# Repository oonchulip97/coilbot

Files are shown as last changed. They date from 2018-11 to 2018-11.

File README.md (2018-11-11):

# Overview
This solenoid winder is able to produce solenoids which are suitable to be used as actuators.

## Boards and Motors
 - Arduino Uno R3
 - Arduino Motor Shield L298P
 - Servo Motor Tower Pro 9G 180
 - Stepper Motor Nema17 12V
   
## Software
 - Arduino IDE (tested using version 1.8.5)
 
## Photos
 
 
 
 
# Setup
 1. Design and manufacture solenoid spool supporter to connect the solenoid spool to the shaft of the stepper motor.
 2. Assemble the solenoid spool and solenoid spool supporter to the shaft of the stepper motor.
 3. Connect the Arduino Uno to computer via the Arduino USB port.
 4. Connect the Arduino Motor Shield to a power source via the 12V power cable.
 5. Place the wire spool and thread the wire through the suitable eye holes and servo arm hole onto the solenoid spool.
 * NOTES: Green eye holes are used for high-tension wire. Red eye holes and wire tensioner are used for low-tension wire.
 
# Calibration
 1. Measure and change the diameter of the wire in the Arduino Sketch.
 2. Adjust the number of revolutions required on the Solenoid Spool in the Arduino Sketch.
 3. Adjust the initial direction of the servo motor as needed in the Arduino Sketch.
 4. Upload the Arduino Sketch onto the Arduino Uno.
 5. Open Serial Monitor.
 6. Type in the initial position (in degrees) of the servo motor so the servo arm hole align with the end of the solenoid spool.
 7. Type in the final position (in degrees) of the servo motor so the servo arm hole align with another end of the solenoid spool.
 8. Type in the start position (in degrees) of the servo motor. Typically, start position is the same as the final position.
 9. Number of revolutions spun, number of revolutions remaining and position of the servo (degrees) will be shown in the Serial Monitor.
 * NOTES: Press the reset button on the Arduino Uno to stop and reset the operation.
 
Coilbot In Action (http://www.youtube.com/watch?v=lM6HLl1aofY "Coilbot In Action")

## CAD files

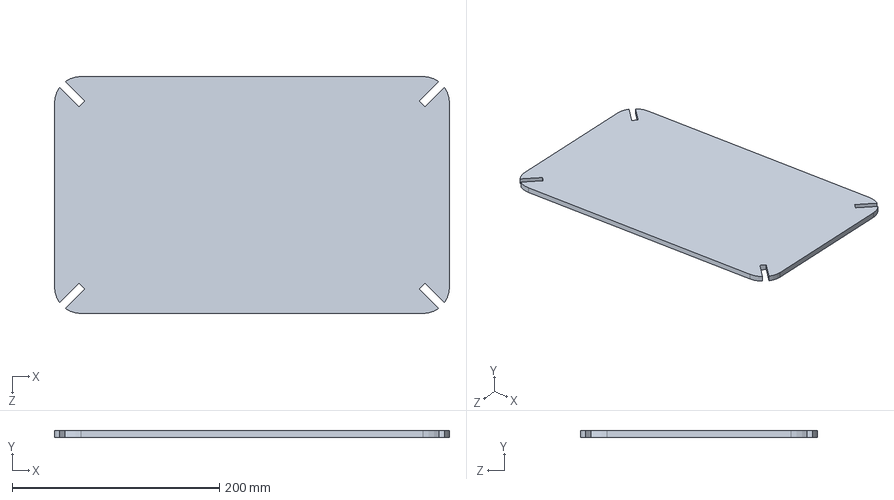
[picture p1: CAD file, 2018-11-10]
SolidWorks/Base/Coilbot Base Support.SLDPRT
381.0 x 6.35 x 228.6 mm

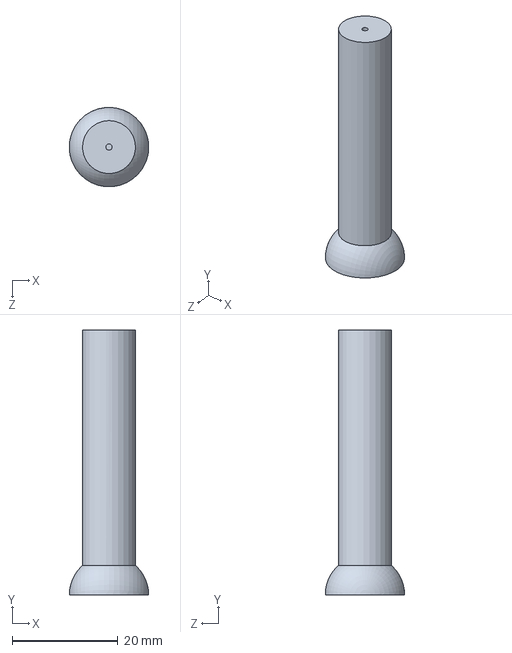
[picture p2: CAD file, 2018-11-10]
SolidWorks/Eye Hole Support/Eye Hole Support-Refined.SLDPRT
15.0 x 50.0 x 15.0 mm

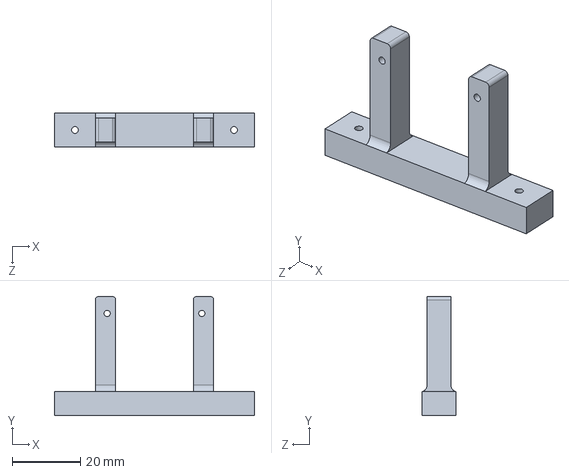
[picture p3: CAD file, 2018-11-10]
SolidWorks/Servo Support/Servo Mount.SLDPRT
58.8 x 35.0 x 10.0 mm

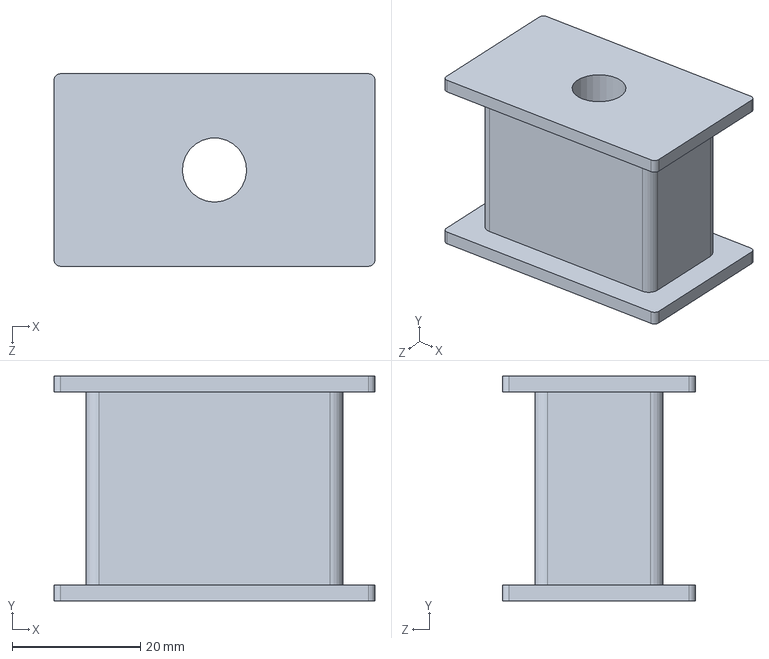
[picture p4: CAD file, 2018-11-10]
SolidWorks/Solenoid Spool/Solenoid Spool.SLDPRT
50.0 x 35.0 x 30.0 mm

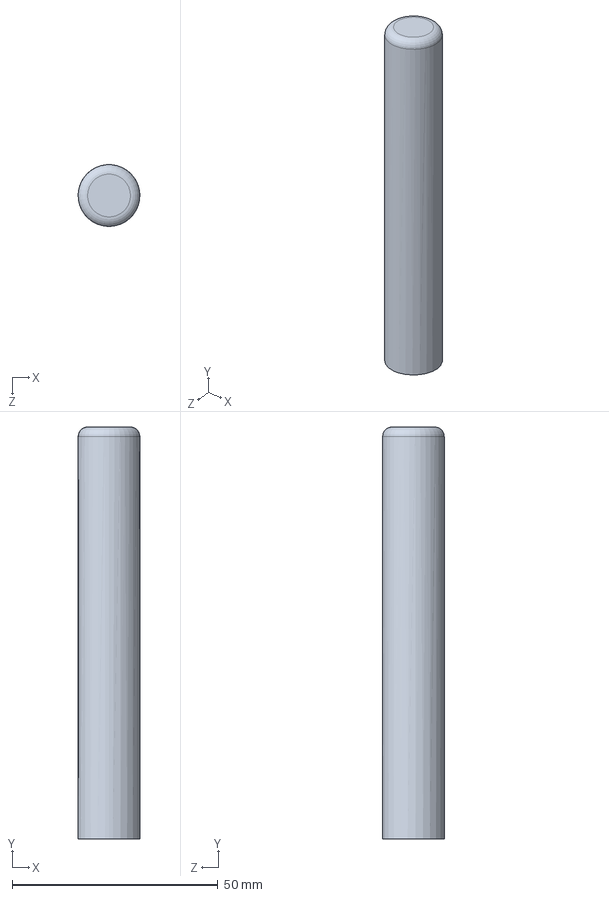
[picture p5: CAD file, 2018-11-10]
SolidWorks/Spool Support/Spool Support.SLDPRT
15.0 x 100.0 x 15.0 mm

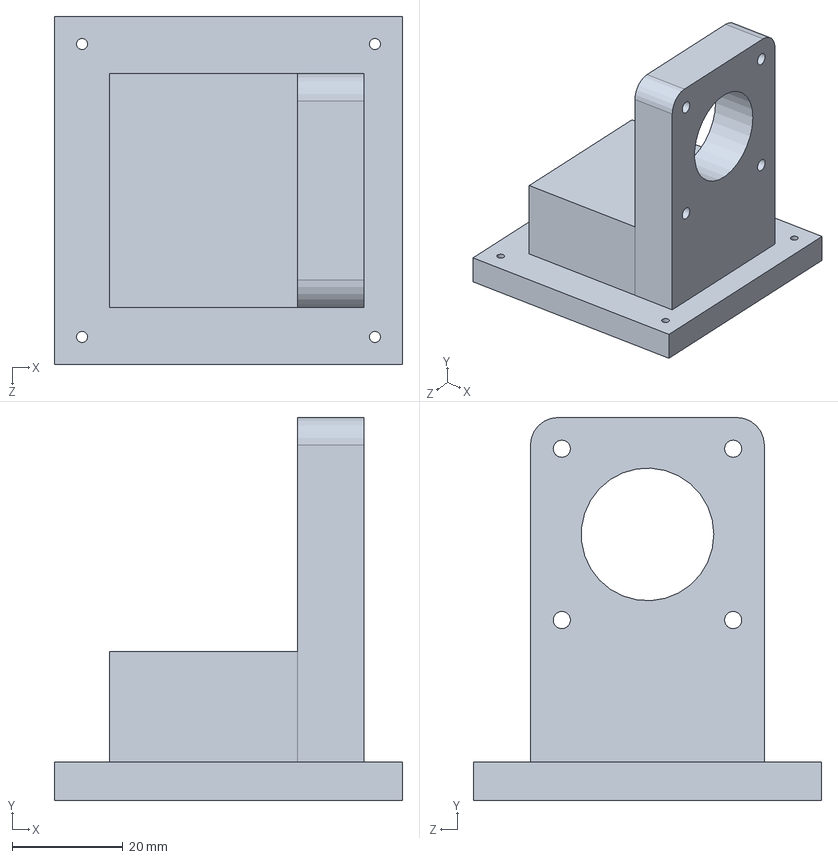
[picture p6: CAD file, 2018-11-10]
SolidWorks/Stepper Support/Stepper Motor Mount.SLDPRT
63.0 x 69.3 x 63.0 mm

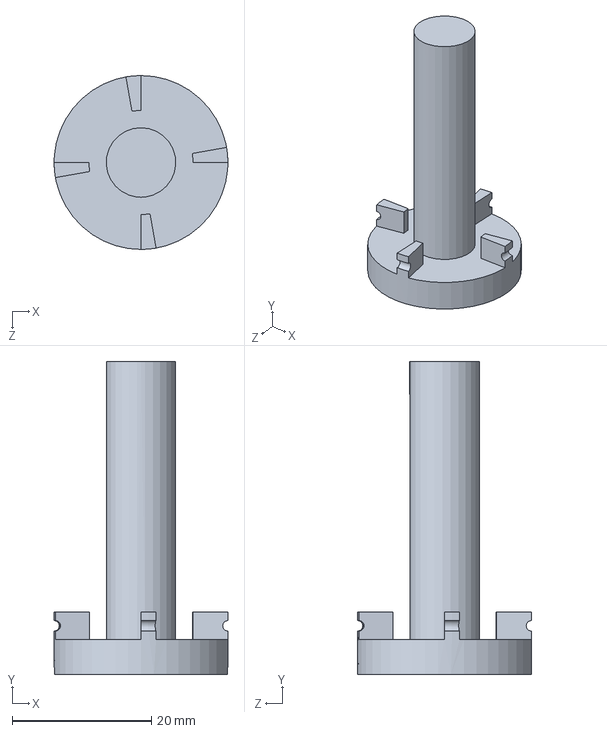
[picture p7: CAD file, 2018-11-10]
SolidWorks/Winder Supporter/UBC Winder Supporter.SLDPRT
25.0 x 45.0 x 25.0 mm

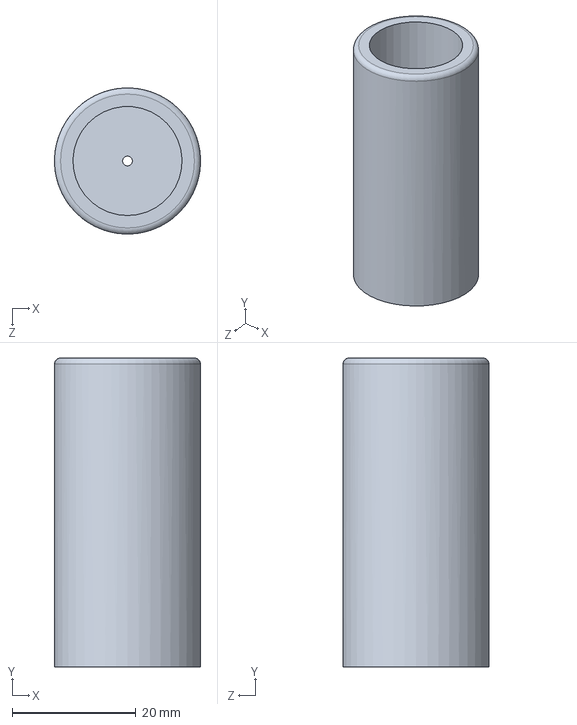
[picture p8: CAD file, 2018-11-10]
SolidWorks/Wire Tensioner/Wire Tensioner Support.SLDPRT
23.6 x 50.0 x 23.6 mm

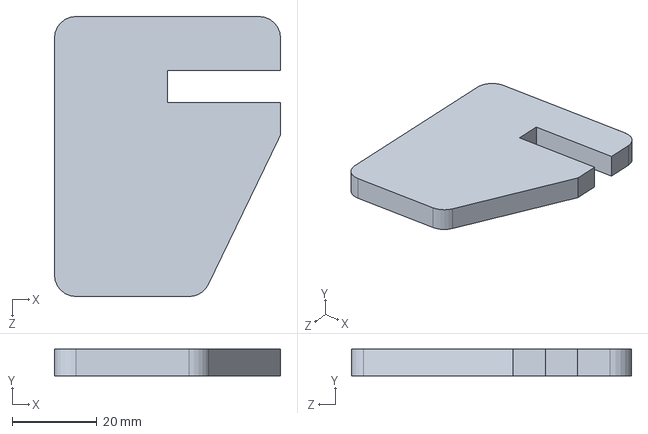
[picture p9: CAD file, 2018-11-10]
SolidWorks/Base/Coilbot Leg.SLDPRT
53.3 x 6.35 x 66.0 mm

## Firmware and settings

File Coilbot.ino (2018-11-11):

// Include necessary library here
#include <Servo.h>

// CHANGE THE FOLLOWING VARIABLES AS REQUIRED
const float wire_diameter = 0.5; // variable to store the diameter of the wire in millimeters
int revolution_required = 691; // variable to store the number of revolution required in the spool
bool moving_forward = false; // variable to store the direction of movement of the servo

// Include variables for servo motor
const float radius_servo_arm = 14.5; // variable to store the radius of the servo arm between the axis of rotation to the wire hole in millimeters
const int servo_pin = 6;  // variable to store the pin number of the servo
const int servo_pwm_min = 612; // variable to store the pulse width, in microseconds, corresponding to the minimum (0-degree) angle on the servo
const int servo_pwm_max = 2148; // variable to store the pulse width, in microseconds, corresponding to the maximum (180-degree) angle on the servo
int initial_deg;  // variable to store the initial position of the servo in degrees
int final_deg;  // variable to store the final position of the servo in degrees
int start_deg;  // variable to store the start position of the servo in degrees
float pos; // variable to store the current position of the servo in degrees (initial current position is start position)
Servo myServo;  // servo object to control a servo

// Include variables for stepper motor
const int pwm_a = 3;  // variable to store the pwm pin A position
const int pwm_b = 9;  // variable to store the pwm pin B position
const int dir_a = 2;  // variable to store the direction pin A position
const int dir_b = 8;  // variable to store the direction pin B position
const int STEPS = 2*200;  // variable to store the total count of halfsteps per full rotation (*2 for half steps!), e.g. 1.8deg stepper => 200 steps => 400 halfsteps
int currStep = 0;  // variable to store the current half step, corresponds to angular position,  limits: 0...STEPS
int sub = 0;  // variable to store the current halfstep within repeating sequence (8 halfsteps for each sequence), limits: 0...7
const int step_dir_per_revolution = -400; // variable to store the number of halfsteps (magnitude) and intended direction (sign) per revolution of the stepper motor
const int step_time = 4000;  // variable to store the wait time between steps in microseconds, bigger means smaller speed and vice versa
int revolution_count = 0; // variable to store the counter for number of revolution spun

void setup() {
  // put your setup code here, to run once:

  myServo.attach(servo_pin, servo_pwm_min, servo_pwm_max);  // attach the servo on the pin to the servo object
  pinMode(pwm_a,OUTPUT);  // initialize the pwm pin A as output
  pinMode(pwm_b,OUTPUT);  // initialize the pwm pin B as output
  pinMode(dir_a,OUTPUT);  // initialize the direction pin A as output
  pinMode(dir_b,OUTPUT);  // initialize the direction pin B as output
  Serial.begin(9600); // set the data rate in bits per second (baud) for serial data transmission
  calibration(); // allow user to set the initial position, final position and start position of the servo
}

void loop() {
  // put your main code here, to run repeatedly:

  myServo.write(pos);  // tell servo to go to position in variable 'pos'
  subStep(step_dir_per_revolution, step_time);  // spin stepper for one revolution
  delay(10);  // wait for both the motors to reach the position
  revolution_count += 1; // increment revolution counter
  Serial.print("Revolution spun:\t"); // display information
  Serial.print(revolution_count); 
  Serial.print("\tRevolution left:\t"); 
  Serial.print(revolution_required - revolution_count); 
  Serial.print("\tPosition:\t"); 
  Serial.println(pos); 

  if (revolution_count >= revolution_required){ // check whether the required number of revolution of wire has been spun onto the spool
    Serial.print("Solenoid wiring has been completed. Total number of revolution:"); // display feedback for completion
    Serial.println(revolution_count); 
    while (true){ // go into infinite loop
    turnOffMotors; // turn off the motors
    }
  }

  // increment or decrement degree interval based on intended movement of the servo
  if (moving_forward && pos < final_deg){ // if servo is moving from initial position to final position
    float deg_interval = (acos(cos(pos*3.14159/180)-(wire_diameter/radius_servo_arm))-pos*3.14159/180)*180/3.14159;   // calculate degree interval when the servo is moving from initial position to final position
    pos += deg_interval; // increment degree interval for next position of the servo
    if (isnan(pos)){ // servo will exceed 180 degrees in the current position
      myServo.write(pos);  // tell servo to go to 180 degrees position
      pos = 180; // set position of servo to 180 degrees
    }
    if (pos >= final_deg){ // if position of the servo is equal or more than final position
      pos = final_deg; // set position of servo to final degrees
      moving_forward = false; // make servo moves from final position to initial position
    }
  }
  else if (!moving_forward && pos > initial_deg){ // if servo is moving from final position to initial position
    float deg_interval = (pos*3.14159/180-acos(cos(pos*3.14159/180)+(wire_diameter/radius_servo_arm)))*180/3.14159;   // calculate degree interval when the servo is moving from final position to initial position
    pos -= deg_interval; // decrement degree interval for next position of the servo
    if (isnan(pos)){ // servo will subceed 0 degrees in the current position
      myServo.write(pos);  // tell servo to go to 0 degrees position
      pos = 0; // set position of servo to 0 degrees
    }
    if (pos <= initial_deg){ // if position of the servo is equal or less than initial position
      pos  = initial_deg; // set position of servo to initial degrees
      moving_forward = true; // make servo moves from initial position to final position
    }
  }
}

// This function is called in order to make the stepper motor make a number of sub steps (depending on your wiring).
// Variable steps is for number of steps (forwards = positive, backwards = negative)
// stepDelay is for waiting time between steps in microseconds => bigger means lower speed, smaller means higher speed

void subStep(long steps, int stepDelay){

  // The function will run for the amount of times called in the method.
  // This is accomplished by a while loop, where it will subtract 1 from the amount after every run (forwards).
  // In case of backward rotation it will add 1 to the negative number of steps until 0 is reached.

  while(steps!=0)
    {

    if(steps>0){currStep++;}       //increment current halfstep (forward)
    if(steps<0){currStep--;}       //decrement current halfstep (backward)

    if(currStep>STEPS){currStep= currStep-STEPS;}         //position >360deg is reached => set position one turn back
    if(currStep<0){currStep= currStep+STEPS;}             //position <0deg   is reached => set position one turn forward

    sub = currStep%8;           //determine the next halfstep

    switch(sub)
    {
           case 0: 
    // Starting position (if repeated, ful step (4))
    // EXPLINATION: in this case, both our power are high.
    // Therefore both coils are activated, with their standard polarities for their magnetic fields.
    digitalWrite(pwm_a,HIGH);
    digitalWrite(pwm_b,HIGH);
    digitalWrite(dir_a,HIGH);
    digitalWrite(dir_b,HIGH);
            break;

            case 1:
    //Half step (½)
    // EXPLINATION: In this case, only out b-coil is active, still with it's stand polarity.
    digitalWrite(pwm_a,HIGH);
    digitalWrite(pwm_b,LOW);
    digitalWrite(dir_a,HIGH);
    digitalWrite(dir_b,LOW);
            break;

    case 2:
            //Full step (1)
    // EXPLINATION: In this case, the b-coil is activated as in previous cases.
    // But the a-coil now has it's direction turned on. So now it's active, but with the reversered polarity.
    // By continuing this pattern (for reference: http://www.8051projects.net/stepper-motor-interfacing/full-step.gif) , you'll get the axis to turn.
    digitalWrite(pwm_a,HIGH);
    digitalWrite(pwm_b,HIGH);
    digitalWrite(dir_a,HIGH);
    digitalWrite(dir_b,LOW);
            break;

    case 3:
    // Half step (1½)
    digitalWrite(pwm_a,LOW);
    digitalWrite(pwm_b,HIGH);
    digitalWrite(dir_a,LOW);
    digitalWrite(dir_b,LOW);
            break;

    case 4:
    // Full step (2)
    digitalWrite(pwm_a,HIGH);
    digitalWrite(pwm_b,HIGH);
    digitalWrite(dir_a,LOW);
    digitalWrite(dir_b,LOW);
            break;

    case 5:
    // Half step (2½)
    digitalWrite(pwm_a,HIGH);
    digitalWrite(pwm_b,LOW);
    digitalWrite(dir_a,LOW);
    digitalWrite(dir_b,LOW);
            break;

    case 6:
    // Full step (3)
    digitalWrite(pwm_a,HIGH);
    digitalWrite(pwm_b,HIGH);
    digitalWrite(dir_a,LOW);
    digitalWrite(dir_b,HIGH);
            break;

    case 7:
    // Half step (3½)
    digitalWrite(pwm_a,LOW);
    digitalWrite(pwm_b,HIGH);
    digitalWrite(dir_a,LOW);
    digitalWrite(dir_b,HIGH);
            break;
    }

    delayMicroseconds(stepDelay);        //Waiting time to next halfstep

    if(steps>0){steps--;}      //decrement of remaining halfsteps of forward rotation
    if(steps<0){steps++;}      //increment of remaining halfsteps of backward rotation
  }
}


// This function simply just turn off the motors, called when ever we don't need the motors anymore.
// In this way, we won't fray the circuit or coils.
// Note 1: Motor has no torque anymore
// Note 2: If current position is between full steps, motor will move for a half step!
void turnOffMotors(){
  digitalWrite(pwm_a,LOW);
  digitalWrite(pwm_b,LOW);
  digitalWrite(dir_a,LOW);
  digitalWrite(dir_b,LOW);
}

// This function allows user to enter a specified position of the servo.
bool userInput(String servo_pos, int &degree){

  String readString;
  bool input_from_user = true;

  Serial.print("Type the "); // display information
  Serial.print(servo_pos);
  Serial.println(" position of the servo (degrees) into the serial port. Click send.");
  while (Serial.available() <= 0){}; // wait for user input
  while (Serial.available()){; // begin after user input
    char c = Serial.read(); // get one character from serial buffer
    readString += c; // add character into the string
    delay(2); // slow looping to allow buffer to fill with next character
  }
    
  degree = readString.toInt(); // convert string into number
  myServo.write(degree); // move servo to the specified position
  readString = ""; // clear string
  Serial.print("Servo is moving to "); // display information
  Serial.print(servo_pos); 
  Serial.print(" position (degrees):\t"); 
  Serial.println(degree);

  while(input_from_user){ // loop until user enters valid input
    Serial.println("Type Y if the position of the servo is correct. Type N to recalibrate the position of the servo. Click Send."); // display user insctructions
    while (Serial.available() <= 0){}; // wait for user input
    char c = Serial.read(); // get the character from the serial buffer
    if(c == 'Y'){ // user type Y
      input_from_user = false; // do not need further user input
      Serial.print("Calibration of "); // display information
      Serial.print(servo_pos); 
      Serial.print(" position (degrees) is completed:\t");
      Serial.println(degree);
      unsigned long now = millis (); // read and discard any input within 200 milliseconds
      while (millis () - now < 200){
        Serial.read ();
      }
      return false; // calibration of the specified position is completed
    }
    else if(c == 'N'){ // user type N
      input_from_user = false; // do not need further user input
      Serial.print("Recalibrate "); // display information
      Serial.print(servo_pos); 
      Serial.println(" position of the servo.");
      unsigned long now = millis (); // read and discard any input within 200 milliseconds
      while (millis () - now < 200){
        Serial.read ();
      }
    }
    else{ // user do not type Y
      Serial.println("Invalid input. Press retry."); // display information
      unsigned long now = millis (); // read and discard any input within 200 milliseconds
      while (millis () - now < 200){
        Serial.read ();
      }
    }
  }
  return true; // calibration of the specified position is incomplete
}

// This function allows user to set initial position, final position and start position of the servo.
void calibration() {

  bool calibrate_initial_deg = true;
  bool calibrate_final_deg = true;
  bool calibrate_start_deg = true;

  Serial.println("Begin calibration for the initial position, final position and start position of the servo.");

  while(calibrate_initial_deg){ // calibrate for initial position of the servo
    calibrate_initial_deg = userInput("initial",initial_deg);
  }

  while(calibrate_final_deg){ // calibrate for final position of the servo
    calibrate_final_deg = userInput("final",final_deg);
  }

  while(calibrate_start_deg){ // calibrate for start position of the servo
    calibrate_start_deg = userInput("start",start_deg);
  }
  
  Serial.println("Calibration for initial position, final position and start position of the servo is completed."); // display information
  Serial.print("Initial position (degrees):\t");
  Serial.print(initial_deg);
  Serial.print("\t");
  Serial.print("Final position (degrees):\t");
  Serial.print(final_deg);
  Serial.print("\t");
  Serial.print("Start position (degrees):\t");
  Serial.println(start_deg);
  pos = start_deg;
}
